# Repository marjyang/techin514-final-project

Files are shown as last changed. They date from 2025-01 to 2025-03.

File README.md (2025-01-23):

# Smart Shower Feedback System

This device focuses on the issue of water usage waste and awareness during long showers - an important issue for utility bills and sustainability.

This system will monitor real-time water usage directly from the shower head (sensing device) and provide feedback to users with a meter and OLED on the other side of the shower wall (display device) to remind users of their water consumption habits. Users will also be able to set weekly water consumption goals.

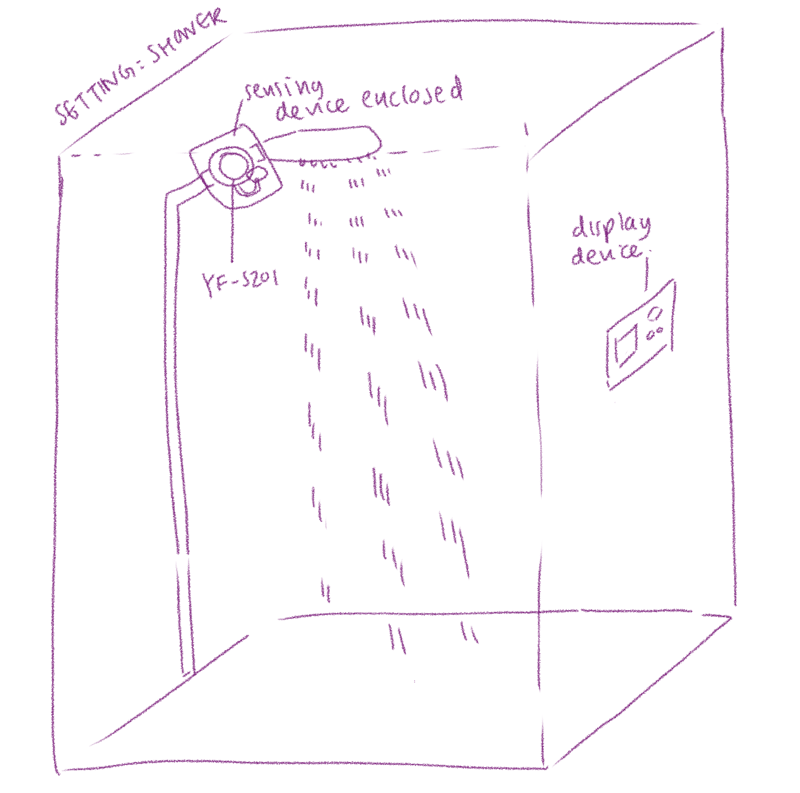
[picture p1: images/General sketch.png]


## The "sensor" device
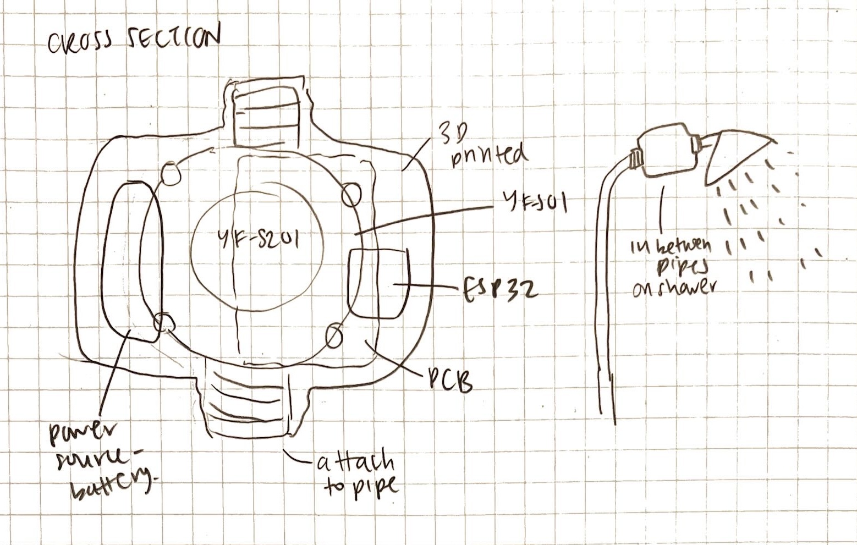
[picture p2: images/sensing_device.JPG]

The sensing device, YF-S201, is connected to the ESP32 from the sensing device, and measures the flow rate of water directly from the showerhead. It generates pulse signals proportional to the water usage, where the ESP32 can process as metrics like total water consumed and flow rate. 

## The "display" device
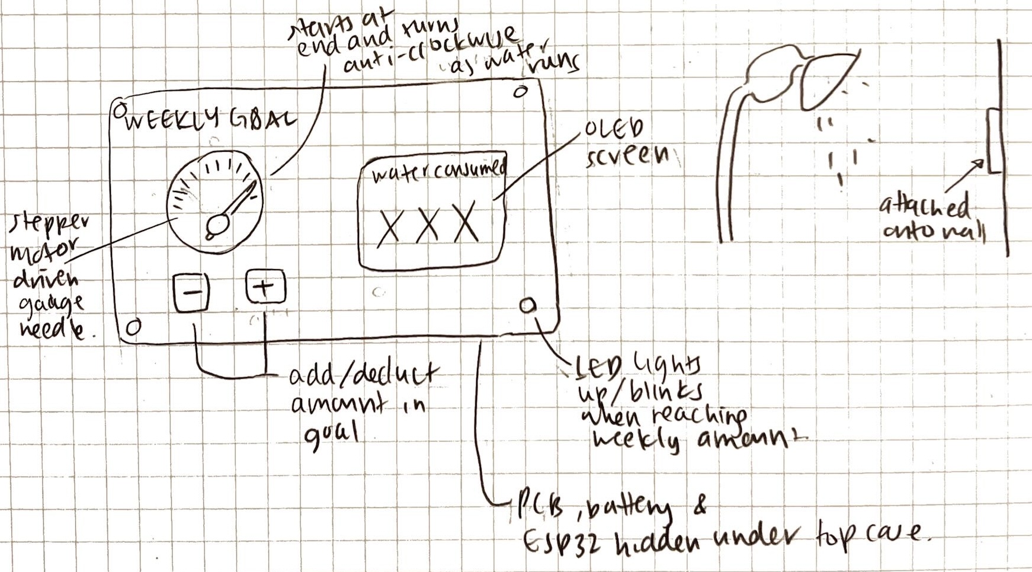
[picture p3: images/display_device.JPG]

The display device has an OLED screen, gauge needle and LEDs controlled by its own ESP32 microcontroller. From the water usage data from the sensing device ESP32, the ESP32 here helps display real-time feedback including water consumed during the week and processes data to track progress toward weekly consumption goal. The buttons connected also allow users to manually adjust the gauge needle or the weekly goal set.

## System Architecture
### Diagram 1
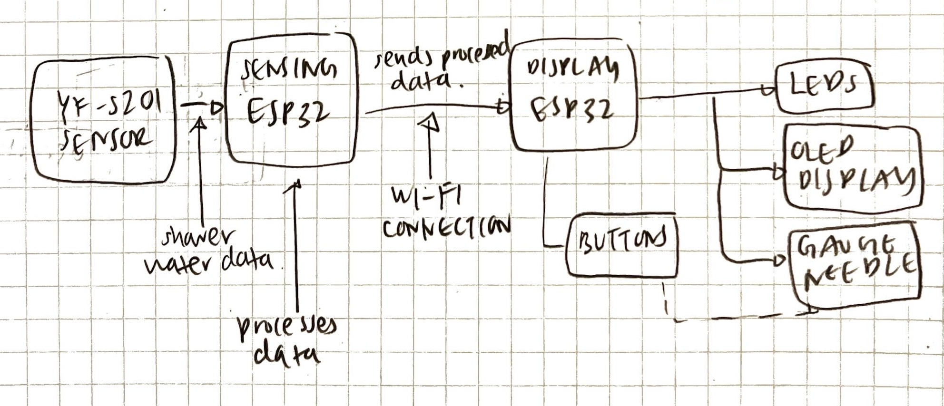
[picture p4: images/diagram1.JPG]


### Diagram 2
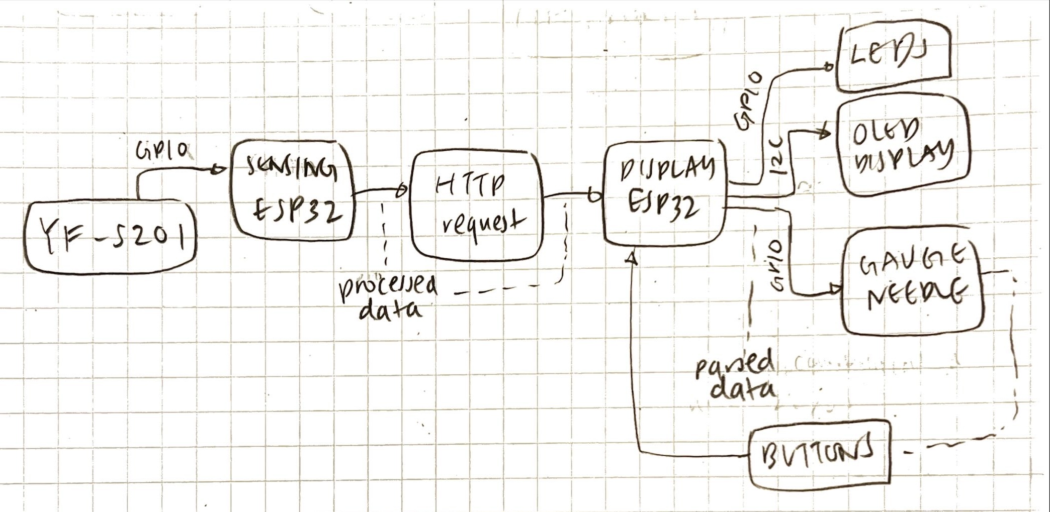
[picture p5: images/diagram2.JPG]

Here, the YF-S201 sensor sends data from the shower through GPIO connection with the sensing device XIAO ESP32, where the data is processed. This ESP32 then through, HTTP request, sends the processed data to the display device ESP32 wirelessly. This ESP32 through GPIO controls the output in the LEDs and another GPIO controlling output in the gauge needle. Through I2C/SPI, the ESP32 displays the processed data onto the SSD1306 OLED display. Buttons are also connected to the GPIO of the ESP32, where input data from interacting with buttons is sent over as data to the gauge needle to control the weekly goal set.

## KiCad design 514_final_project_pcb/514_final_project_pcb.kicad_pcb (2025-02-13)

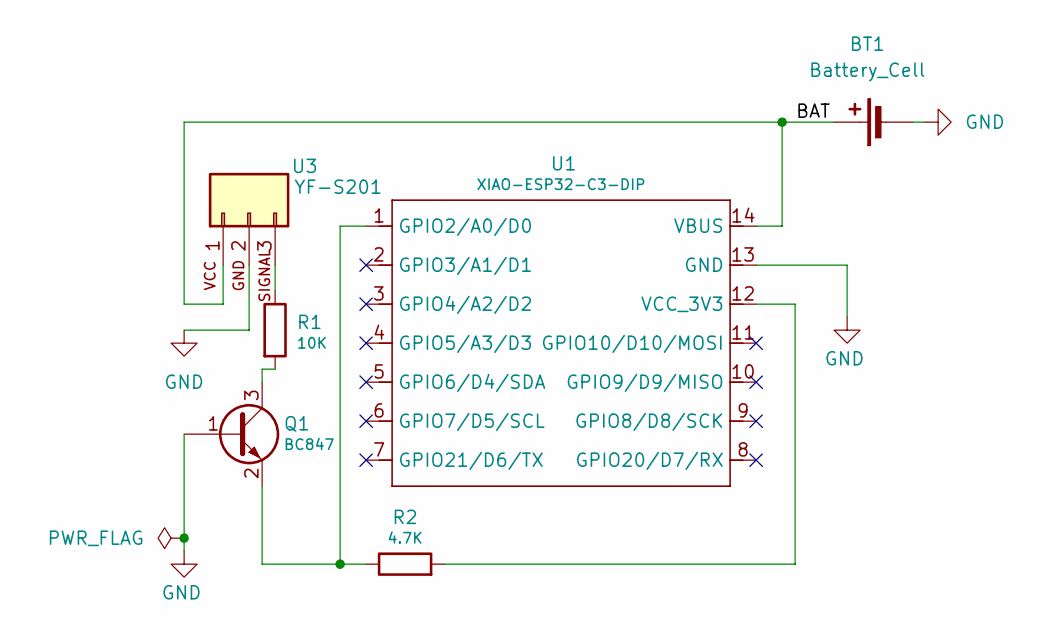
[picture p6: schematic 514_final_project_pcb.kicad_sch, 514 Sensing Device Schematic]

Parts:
BT1: Battery_Cell; JST_NV_B02P-NV_1x02_P5.00mm_Vertical
Q1: BC847; SOT-23
R1: 10K; R_0805_2012Metric
R2: 4.7K; R_0805_2012Metric
U1: XIAO-ESP32-C3-DIP; XIAO-ESP32C3-DIP
U3: YF-S201; PinSocket_1x03_P2.54mm_Vertical

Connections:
/BAT: BT1.1 (+), U1.14 (VBUS), U3.1 (VCC)
GND: BT1.2 (-), Q1.1 (B), U1.13 (GND), U3.2 (GND)
unnamed: Q1.3 (C), R1.2
unnamed: Q1.2 (E), R2.1, U1.1 (GPIO2/A0/D0)
unnamed: R2.2, U1.12 (VCC_3V3)
unnamed: R1.1, U3.3 (SIGNAL)

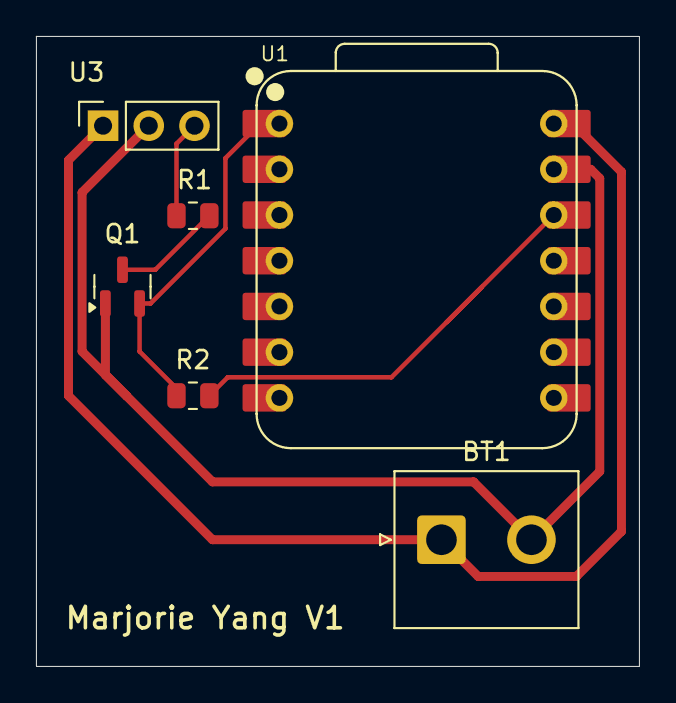
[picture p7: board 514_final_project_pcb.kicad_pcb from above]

Board: 2 copper layers, 33.5 x 35.0 mm, 6 parts (0 on the bottom side), 6 nets.

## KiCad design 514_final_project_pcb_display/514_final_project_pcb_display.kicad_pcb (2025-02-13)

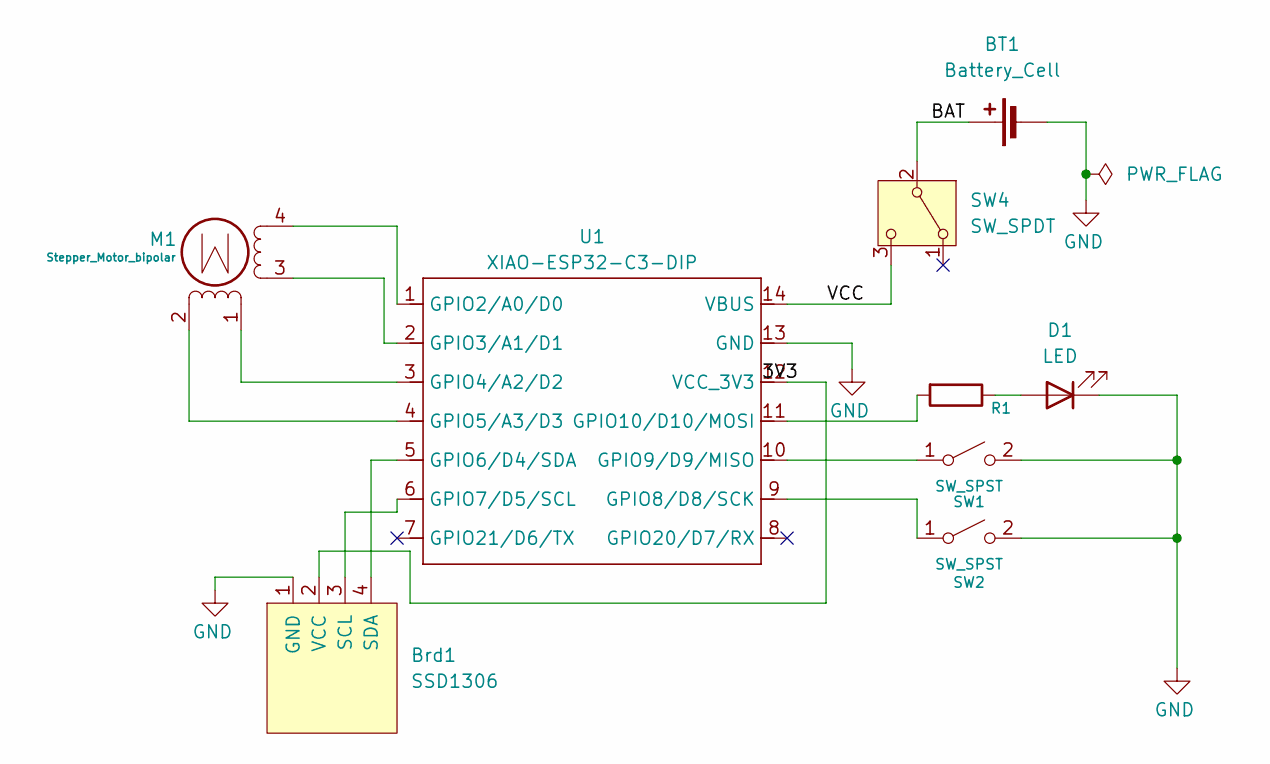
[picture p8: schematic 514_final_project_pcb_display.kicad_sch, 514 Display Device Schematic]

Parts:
BT1: Battery_Cell; JST_NV_B02P-NV_1x02_P5.00mm_Vertical
Brd1: SSD1306; 128x64OLED
D1: LED; LED_1206_3216Metric
M1: Stepper_Motor_bipolar; x27_stepper
R1: 220; R_0603_1608Metric
SW1, SW2: SW_SPST; SW_PUSH-12mm
SW4: SW_SPDT; JST_EH_B3B-EH-A_1x03_P2.50mm_Vertical
U1: XIAO-ESP32-C3-DIP; XIAO-ESP32C3-DIP

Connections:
/BAT: BT1.1 (+), SW4.2 (B)
/VCC: SW4.3 (C), U1.14 (VBUS)
GND: BT1.2 (-), Brd1.1 (GND), D1.1 (K), SW1.2 (B), SW2.2 (B), U1.13 (GND)
unnamed: Brd1.3 (SCL), U1.6 (GPIO7/D5/SCL)
unnamed: Brd1.4 (SDA), U1.5 (GPIO6/D4/SDA)
unnamed: Brd1.2 (VCC), U1.12 (VCC_3V3)
unnamed: D1.2 (A), R1.1
unnamed: M1.2 (-), U1.4 (GPIO5/A3/D3)
unnamed: SW1.1 (A), U1.10 (GPIO9/D9/MISO)
unnamed: SW2.1 (A), U1.9 (GPIO8/D8/SCK)
unnamed: M1.4, U1.1 (GPIO2/A0/D0)
unnamed: M1.3, U1.2 (GPIO3/A1/D1)
unnamed: M1.1, U1.3 (GPIO4/A2/D2)
unnamed: R1.2, U1.11 (GPIO10/D10/MOSI)

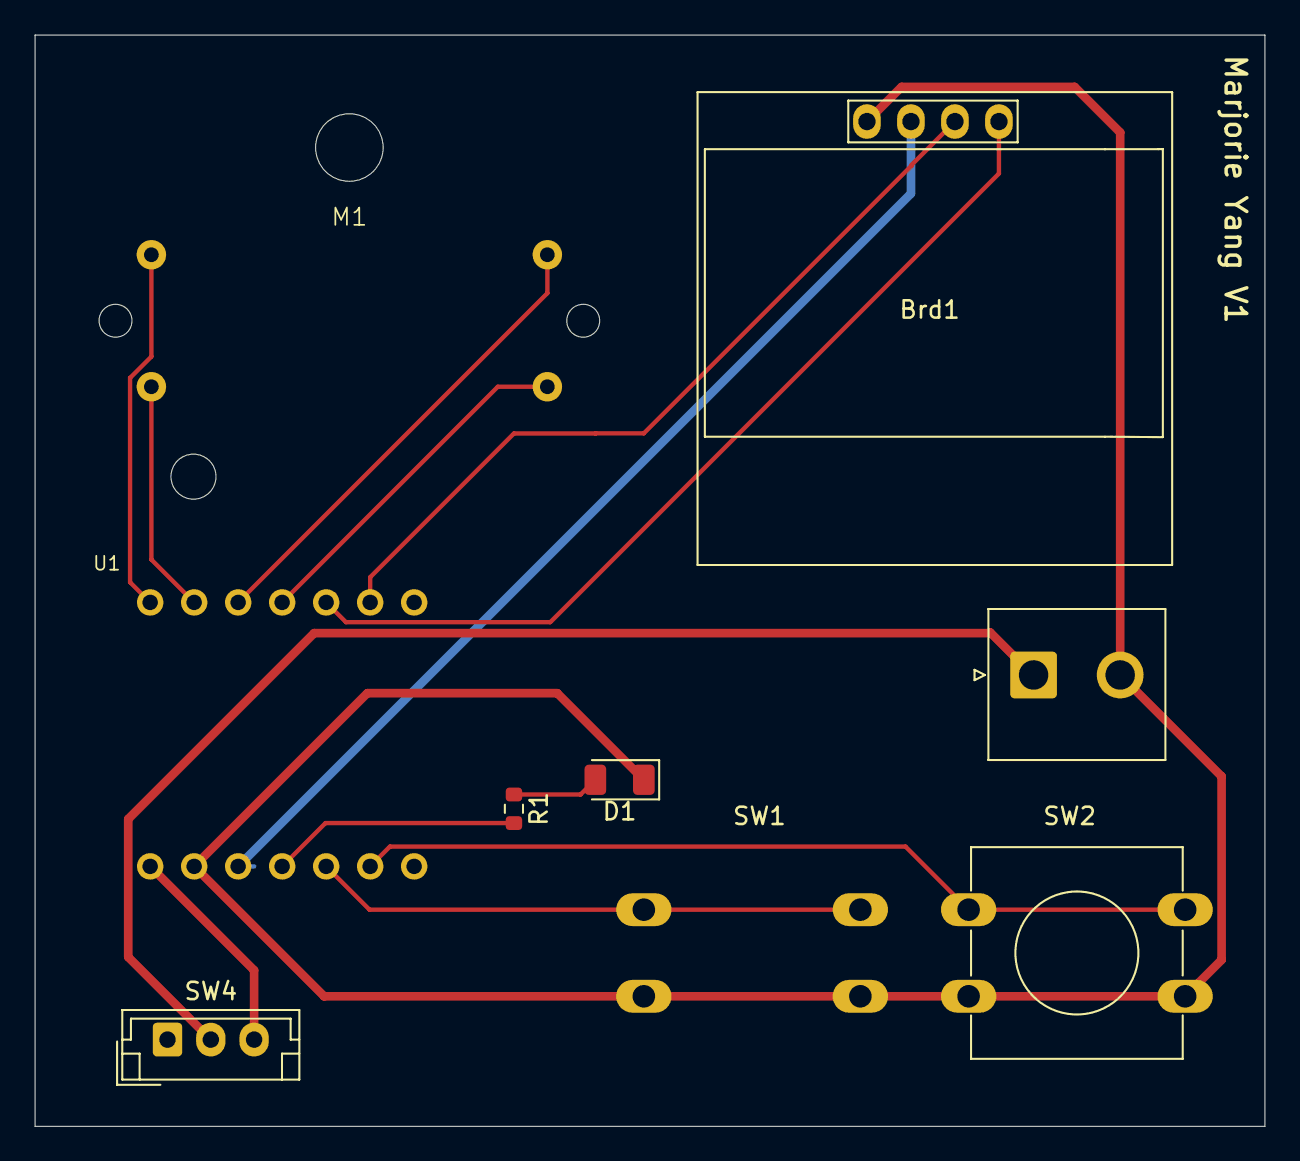
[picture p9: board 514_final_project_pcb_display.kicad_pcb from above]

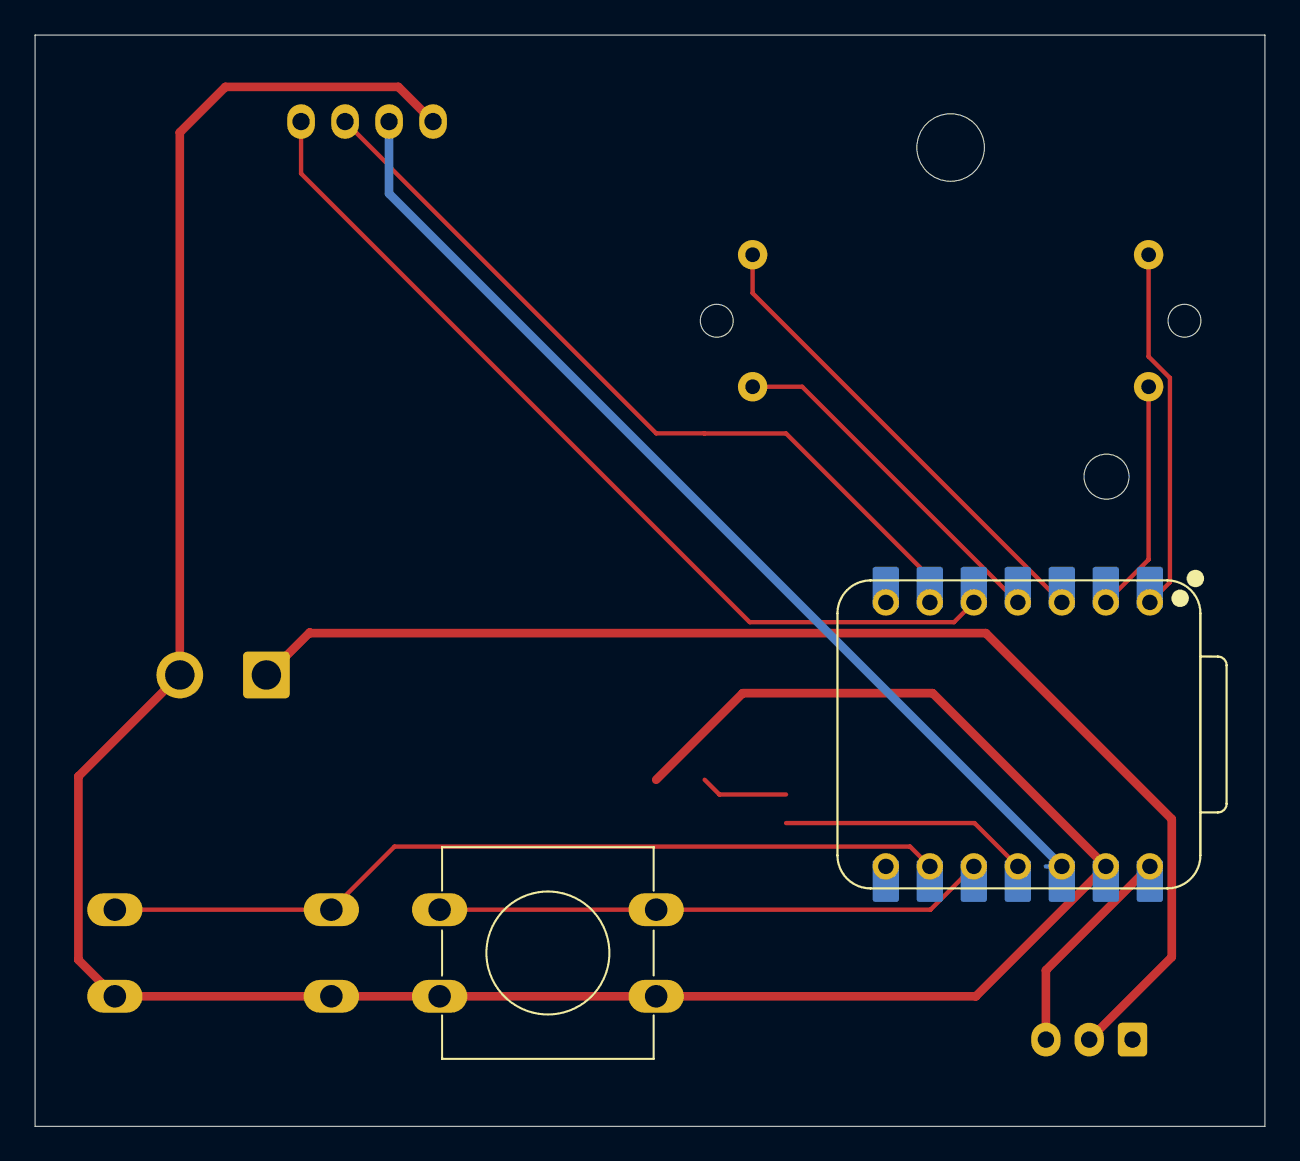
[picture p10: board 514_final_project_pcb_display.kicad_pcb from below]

Board: 2 copper layers, 71.0 x 63.0 mm, 9 parts (2 on the bottom side), 14 nets.

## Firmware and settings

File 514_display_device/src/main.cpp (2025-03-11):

#include <Wire.h>
#include <Adafruit_GFX.h>
#include <Arduino.h>
#include <Adafruit_SSD1306.h>
#include <BLEDevice.h>
#include <BLEUtils.h>
#include <BLEClient.h>
#include <BLEScan.h>
#include <BLEAdvertisedDevice.h>

// **OLED Configuration**
#define SCREEN_WIDTH 128
#define SCREEN_HEIGHT 64
#define OLED_RESET    -1  
#define I2C_ADDRESS   0x3C

#define SDA_PIN 6
#define SCL_PIN 7

Adafruit_SSD1306 display(SCREEN_WIDTH, SCREEN_HEIGHT, &Wire, OLED_RESET);

// **Stepper Motor Configuration**
#define MOTOR_PIN_1 0  
#define MOTOR_PIN_2 1  
#define MOTOR_PIN_3 2  
#define MOTOR_PIN_4 3  

int stepPosition = 0;    // Tracks current stepper position
const int maxSteps = 160; // Maximum stepper position
const int minSteps = 0;   // Minimum stepper position

// **Stepper Motor Step Sequence**
const int stepSequence[4][4] = {
    {1, 0, 1, 0},  
    {0, 1, 1, 0},  
    {0, 1, 0, 1},  
    {1, 0, 0, 1}   
};

// **Water Consumption Variables**
float numerator = 0.0;    // Water consumed
float denominator = 30.0; // Water consumption goal
float initialOffset = 0.0; // Offset to subtract from received values
bool firstDataReceived = false; // Flag to track if we've received initial data

// **Button Pins**
#define BUTTON_UP 8
#define BUTTON_DOWN 9

// **LED Pin**
#define LED_PIN 10  

// **BLE UUIDs**
#define SERVICE_UUID        "6ffd810a-1f60-43df-aa2f-cb68a815285f"
#define CHARACTERISTIC_UUID "7ca0eada-bb21-4d31-8c72-e52221ea4409"

static BLEUUID serviceUUID(SERVICE_UUID);
static BLEUUID charUUID(CHARACTERISTIC_UUID);
static boolean doConnect = false;
static boolean connected = false;
static boolean doScan = false;
static BLEAdvertisedDevice* myDevice;
BLEClient* pClient = NULL;
BLEScan* pBLEScan = NULL;

// **Function Prototypes**
void resetStepper();
void resetStepperToZero();
void moveStepperToPosition(int targetStep);
void moveStepperForward(int steps = 1);
void moveStepperBackward(int steps = 1);
void updateDisplay();
void resetVariables();
bool connectToServer();
void handleButtonPress();

// Reset all variables to starting values
void resetVariables() {
    Serial.println("Resetting variables for new connection");
    initialOffset = 0.0;     // Clear the offset
    numerator = 0.0;         // Reset water consumption
    firstDataReceived = false; // Reset first data flag
    updateDisplay();         // Update the display to show zero
}

// **BLE Client Callback**
class MyClientCallback : public BLEClientCallbacks {
    void onConnect(BLEClient* pClient) { 
        connected = true; 
        Serial.println("✅ Connected to BLE Server!");
    }
    
    void onDisconnect(BLEClient* pClient) { 
        connected = false; 
        Serial.println("❌ Disconnected from BLE Server!");
        // Reset variables when disconnected
        resetVariables();
        doScan = true;  // Restart scanning when disconnected
    }
};

// **BLE Scan Callback**
class MyAdvertisedDeviceCallbacks: public BLEAdvertisedDeviceCallbacks {
    void onResult(BLEAdvertisedDevice advertisedDevice) {
        // Print basic device info
        Serial.print("🔍 BLE Device found: ");
        Serial.print("Name: \"");
        Serial.print(advertisedDevice.getName().c_str());
        Serial.print("\", Address: ");
        Serial.print(advertisedDevice.getAddress().toString().c_str());
        
        // Show RSSI
        Serial.print(", RSSI: ");
        Serial.print(advertisedDevice.getRSSI());
        
        // Check for service UUIDs and print them if available
        if (advertisedDevice.haveServiceUUID()) {
            Serial.print(", Service UUIDs: ");
            for (int i = 0; i < advertisedDevice.getServiceUUIDCount(); i++) {
                Serial.print(advertisedDevice.getServiceUUID(i).toString().c_str());
                Serial.print(" ");
            }
            
            // Extra diagnostic for our specific service UUID
            Serial.print(" [Looking for: ");
            Serial.print(serviceUUID.toString().c_str());
            Serial.print("]");
            
            // Check if device has our service UUID
            if (advertisedDevice.isAdvertisingService(serviceUUID)) {
                Serial.print(" ✓ MATCH FOUND!");
            } else {
                Serial.print(" ✗ No match");
            }
        } else {
            Serial.print(", No Service UUIDs advertised");
        }
        
        Serial.println();
        
        // Connect if it's our device
        if (advertisedDevice.haveServiceUUID() && advertisedDevice.isAdvertisingService(serviceUUID)) {
            BLEDevice::getScan()->stop();
            myDevice = new BLEAdvertisedDevice(advertisedDevice);
            doConnect = true;
            doScan = false;
            Serial.println("🎯 Found our water tracker device! Connecting...");
        }
    }
};

// **BLE Notification Callback**
static void notifyCallback(
    BLERemoteCharacteristic* pRemoteCharacteristic,
    uint8_t* pData,
    size_t length,
    bool isNotify) {

    Serial.println("\n📥 BLE Notification Received! 📥");
    Serial.print("Characteristic UUID: ");
    Serial.println(pRemoteCharacteristic->getUUID().toString().c_str());
    Serial.print("Data Length: ");
    Serial.println(length);

    // Print raw byte data in multiple formats
    Serial.println("🔍 RAW DATA:");
    Serial.print("   HEX: ");
    for (size_t i = 0; i < length; i++) {
        Serial.print(pData[i], HEX);
        Serial.print(" ");
    }
    Serial.println();
    
    Serial.print("   DEC: ");
    for (size_t i = 0; i < length; i++) {
        Serial.print((int)pData[i]);
        Serial.print(" ");
    }
    Serial.println();
    
    Serial.print("   ASCII: ");
    for (size_t i = 0; i < length; i++) {
        if (pData[i] >= 32 && pData[i] <= 126) { // Printable ASCII
            Serial.print((char)pData[i]);
        } else {
            Serial.print(".");
        }
    }
    Serial.println();

    // Convert raw bytes to a string
    String receivedData = "";
    for (size_t i = 0; i < length; i++) {
        receivedData += (char)pData[i];
    }

    Serial.print("📝 String Representation: '");
    Serial.print(receivedData);
    Serial.println("'");

    // Try to convert the received string to a float
    float totalLiters = 0.0;
    bool validData = true;
    
    // Basic validation to check if data is a valid number
    for (size_t i = 0; i < receivedData.length(); i++) {
        char c = receivedData.charAt(i);
        if (!isdigit(c) && c != '.' && c != '-') {
            validData = false;
            Serial.print("Invalid character detected: '");
            Serial.print(c);
            Serial.print("' at position ");
            Serial.println(i);
            break;
        }
    }
    
    if (validData) {
        totalLiters = atof(receivedData.c_str());
        Serial.print("✅ Parsed as Number: ");
        Serial.println(totalLiters);
    } else {
        Serial.println("⚠️ Invalid data format received! Could not parse as number.");
        return;
    }

    if (totalLiters >= 0) {  
        // If this is the first data received, set the offset
        if (!firstDataReceived) {
            initialOffset = totalLiters;
            firstDataReceived = true;
            Serial.print("📏 Set initial offset to: ");
            Serial.println(initialOffset);
        }
        
        // Apply offset to the received value
        float adjustedLiters = totalLiters - initialOffset;
        if (adjustedLiters < 0) adjustedLiters = 0;  // Ensure we don't go negative
        
        Serial.print("✅ Raw Water Consumption: ");
        Serial.print(totalLiters);
        Serial.println(" L");
        
        Serial.print("✅ Adjusted Water Consumption: ");
        Serial.print(adjustedLiters);
        Serial.println(" L");

        numerator = adjustedLiters;  // Store water consumed as float
        Serial.print("Current Goal: ");
        Serial.print(denominator);
        Serial.println(" L");

        // Calculate the stepper position based on the water consumption ratio
        int targetStep = map(numerator * 10, 0, denominator * 10, minSteps, maxSteps); // Multiply by 10 for better precision
        targetStep = constrain(targetStep, minSteps, maxSteps); 

        Serial.print("🚀 Moving Stepper to Step: ");
        Serial.print(targetStep);
        Serial.print(" (from ");
        Serial.print(stepPosition);
        Serial.println(")");

        moveStepperToPosition(targetStep);
        updateDisplay();
    } else {
        Serial.println("⚠️ Failed to process BLE Data! Negative value received.");
    }
}

// **BLE Connection Function**
bool connectToServer() {
    Serial.println("\n🔌 CONNECTING TO BLE SERVER 🔌");
    Serial.print("Device Address: ");
    Serial.println(myDevice->getAddress().toString().c_str());
    Serial.print("Device Name: ");
    Serial.println(myDevice->getName().c_str());
    
    // List all advertised services
    Serial.println("Advertised Services:");
    if (myDevice->haveServiceUUID()) {
        for (int i = 0; i < myDevice->getServiceUUIDCount(); i++) {
            Serial.print("  - ");
            Serial.println(myDevice->getServiceUUID(i).toString().c_str());
        }
    } else {
        Serial.println("  No services advertised");
    }

    // Clean up previous client if it exists
    if (pClient != NULL) {
        delete pClient;
    }
    
    pClient = BLEDevice::createClient();
    pClient->setClientCallbacks(new MyClientCallback());

    // Connect to the remote BLE Server
    Serial.println("Attempting connection...");
    if (!pClient->connect(myDevice)) {
        Serial.println("❌ Failed to connect to BLE server.");
        return false;
    }
    Serial.println("Connected to device!");

    // Discover all services on device
    Serial.println("\n📋 DISCOVERING SERVICES 📋");
    pClient->getServices();
    
    // Obtain a reference to the service we are after
    Serial.print("Looking for service UUID: ");
    Serial.println(serviceUUID.toString().c_str());
    
    BLERemoteService* pRemoteService = pClient->getService(serviceUUID);
    if (pRemoteService == nullptr) {
        Serial.println("❌ Failed to find our target service!");
        Serial.println("Available services on device:");
        
        // List all available services for debugging
        std::map<std::string, BLERemoteService*>* serviceMap = pClient->getServices();
        for(std::map<std::string, BLERemoteService*>::iterator it = serviceMap->begin(); it != serviceMap->end(); ++it) {
            Serial.print("  - ");
            Serial.println(it->first.c_str());
        }
        
        pClient->disconnect();
        return false;
    }
    Serial.println("✅ Found our service!");

    // Find all characteristics for this service
    Serial.println("\n🔍 DISCOVERING CHARACTERISTICS 🔍");
    Serial.print("Looking for characteristic UUID: ");
    Serial.println(charUUID.toString().c_str());
    
    // List all characteristics of the service
    std::map<std::string, BLERemoteCharacteristic*>* charMap = pRemoteService->getCharacteristics();
    Serial.println("Available characteristics:");
    for(std::map<std::string, BLERemoteCharacteristic*>::iterator it = charMap->begin(); it != charMap->end(); ++it) {
        Serial.print("  - ");
        Serial.print(it->first.c_str());
        
        // Show properties
        BLERemoteCharacteristic* pChar = it->second;
        Serial.print(" (Properties: ");
        if(pChar->canRead()) Serial.print("READ ");
        if(pChar->canWrite()) Serial.print("WRITE ");
        if(pChar->canNotify()) Serial.print("NOTIFY ");
        if(pChar->canIndicate()) Serial.print("INDICATE ");
        Serial.println(")");
    }
    
    // Obtain a reference to our target characteristic
    BLERemoteCharacteristic* pRemoteCharacteristic = pRemoteService->getCharacteristic(charUUID);
    if (pRemoteCharacteristic == nullptr) {
        Serial.println("❌ Failed to find our target characteristic!");
        pClient->disconnect();
        return false;
    }
    Serial.println("✅ Found our characteristic!");

    // Read initial value if possible
    if (pRemoteCharacteristic->canRead()) {
        std::string value = pRemoteCharacteristic->readValue();
        Serial.println("\n📊 INITIAL DATA READING 📊");
        Serial.print("Raw value: '");
        Serial.print(value.c_str());
        Serial.println("'");
        
        // Show bytes in hex for debugging
        Serial.print("Hex: ");
        for (int i = 0; i < value.length(); i++) {
            Serial.print((uint8_t)value[i], HEX);
            Serial.print(" ");
        }
        Serial.println();
    } else {
        Serial.println("❗ Characteristic is not readable");
    }

    // Register for notifications if supported
    if (pRemoteCharacteristic->canNotify()) {
        pRemoteCharacteristic->registerForNotify(notifyCallback);
        Serial.println("✅ Successfully registered for notifications");
    } else {
        Serial.println("❗ Characteristic does not support notifications");
    }

    Serial.println("\n✅ BLE CONNECTION COMPLETE ✅");
    connected = true;
    return true;
}

// **Initialize stepper to zero position - turns back 170 steps**
void resetStepperToZero() {
    Serial.println("🔄 Initializing stepper motor - moving backward 170 steps");
    digitalWrite(LED_PIN, HIGH);  // Turn on LED during reset

    // Move backward 170 steps regardless of current position
    for (int i = 0; i < 170; i++) {
        moveStepperBackward(1);
        delay(10);  // Small delay between steps
    }
    
    // Reset position counter
    stepPosition = 0;
    
    digitalWrite(LED_PIN, LOW);  // Turn off LED when done
    Serial.println("✅ Stepper reset complete");
}

// **Reset Stepper Based on Water Consumption Ratio**
void resetStepper() {
    Serial.println("Resetting stepper to match water consumed ratio...");
    digitalWrite(LED_PIN, HIGH);

    // Calculate target step based on current water ratio
    int targetStep = map(numerator * 10, 0, denominator * 10, minSteps, maxSteps);
    targetStep = constrain(targetStep, minSteps, maxSteps);
    
    moveStepperToPosition(targetStep); 

    digitalWrite(LED_PIN, LOW);
    updateDisplay();
}

// **Move Stepper to Specific Position**
void moveStepperToPosition(int targetStep) {
    Serial.print("🚀 Moving Stepper to Position: ");
    Serial.println(targetStep);

    targetStep = constrain(targetStep, minSteps, maxSteps);

    // More efficient movement by calculating number of steps needed
    int stepsToMove = targetStep - stepPosition;
    
    if (stepsToMove > 0) {
        moveStepperForward(stepsToMove);
    } else if (stepsToMove < 0) {
        moveStepperBackward(abs(stepsToMove));
    }
    
    stepPosition = targetStep;
}

// **Stepper Motor Control Functions - Optimized for multi-step movement**
void moveStepperForward(int steps) {
    for (int i = 0; i < steps; i++) {
        for (int step = 0; step < 4; step++) {
            digitalWrite(MOTOR_PIN_1, stepSequence[step][0]);
            digitalWrite(MOTOR_PIN_2, stepSequence[step][1]);
            digitalWrite(MOTOR_PIN_3, stepSequence[step][2]);
            digitalWrite(MOTOR_PIN_4, stepSequence[step][3]);
            delay(10);
        }
    }
}

void moveStepperBackward(int steps) {
    for (int i = 0; i < steps; i++) {
        for (int step = 0; step < 4; step++) {
            int s = 3 - step;
            digitalWrite(MOTOR_PIN_1, stepSequence[s][0]);
            digitalWrite(MOTOR_PIN_2, stepSequence[s][1]);
            digitalWrite(MOTOR_PIN_3, stepSequence[s][2]);
            digitalWrite(MOTOR_PIN_4, stepSequence[s][3]);
            delay(10);
        }
    }
}

// **Update OLED Display with Progress Bar**
void updateDisplay() {
    display.clearDisplay();
    
    // Title
    display.setTextSize(1);
    display.setTextColor(SSD1306_WHITE);
    display.setCursor(0, 0);
    display.println("Water Consumption:");
    
    // Water values with decimals
    display.setTextSize(2);
    display.setCursor(5, 16);
    
    // Format numbers with 1 decimal place
    char waterValue[16];
    char goalValue[16];
    dtostrf(numerator, 4, 1, waterValue); // Convert float to string with 1 decimal
    dtostrf(denominator, 4, 1, goalValue); // Convert float to string with 1 decimal
    
    // Remove leading spaces that dtostrf might add
    char* trimmedWater = waterValue;
    while(*trimmedWater == ' ') trimmedWater++;
    
    char* trimmedGoal = goalValue;
    while(*trimmedGoal == ' ') trimmedGoal++;
    
    // Display the formatted water values
    display.print(trimmedWater);
    display.print("/");
    display.print(trimmedGoal);
    display.println("L");

    // Draw a progress bar
    int barWidth = map(numerator * 10, 0, denominator * 10, 0, 108); // Multiply by 10 for better precision
    barWidth = constrain(barWidth, 0, 108);
    display.drawRect(10, 40, 108, 15, SSD1306_WHITE);
    display.fillRect(10, 40, barWidth, 15, SSD1306_WHITE);
    
    // Show percentage
    float percentage = (numerator / denominator) * 100.0;
    display.setTextSize(1);
    display.setCursor(40, 56);
    display.print(percentage, 1); // Display percentage with 1 decimal place
    display.print("% Full");
    
    display.display();
}

// **Button Press Handling**
void handleButtonPress() {
    // Non-blocking button checking
    static unsigned long lastButtonTime = 0;
    unsigned long currentTime = millis();
    
    if (currentTime - lastButtonTime >= 200) {  // Debounce time
        if (digitalRead(BUTTON_UP) == LOW) {
            denominator += 2.5; 
            if (denominator > 100.0) denominator = 100.0;  // Limit max goal
            Serial.print("🎯 New Goal: ");
            Serial.println(denominator);
            updateDisplay();
            lastButtonTime = currentTime;
        }

        if (digitalRead(BUTTON_DOWN) == LOW) {
            denominator -= 2.5;
            if (denominator < 5.0) denominator = 5.0;  // Avoid zero
            Serial.print("🎯 New Goal: ");
            Serial.println(denominator);
            updateDisplay();
            lastButtonTime = currentTime;
        }
    }
}

// **Setup Function**
void setup() {
    Serial.begin(115200);
    Serial.println("\n\n🚀 Starting up water tracker device...");
    delay(1000);

    // Initialize I2C and OLED
    Wire.begin(SDA_PIN, SCL_PIN);
    if(!display.begin(SSD1306_SWITCHCAPVCC, I2C_ADDRESS)) {
        Serial.println("SSD1306 allocation failed");
        for(;;); // Don't proceed, loop forever
    }
    
    // Set up IO pins
    pinMode(BUTTON_UP, INPUT_PULLUP);
    pinMode(BUTTON_DOWN, INPUT_PULLUP);
    pinMode(LED_PIN, OUTPUT);
    pinMode(MOTOR_PIN_1, OUTPUT);
    pinMode(MOTOR_PIN_2, OUTPUT);
    pinMode(MOTOR_PIN_3, OUTPUT);
    pinMode(MOTOR_PIN_4, OUTPUT);

    // Reset all variables to starting values
    resetVariables();

    // Show startup message
    display.clearDisplay();
    display.setTextSize(1);
    display.setTextColor(SSD1306_WHITE);
    display.setCursor(0, 0);
    display.println("Water Tracker");
    display.println("Starting...");
    display.println("Initializing motor");
    display.display();

    // First reset stepper to zero position by moving back 170 steps
    resetStepperToZero();
    
    // Update display with zeroed position
    updateDisplay();
    
    display.setCursor(0, 40);
    display.println("Setting up BLE...");
    display.display();

    // Initialize BLE
    BLEDevice::init("Display_Device");
    
    // Initialize BLE scan
    pBLEScan = BLEDevice::getScan();
    pBLEScan->setAdvertisedDeviceCallbacks(new MyAdvertisedDeviceCallbacks());
    pBLEScan->setActiveScan(true);
    pBLEScan->setInterval(100);
    pBLEScan->setWindow(99);
    
    // Begin scanning for BLE devices
    doScan = true;
    
    Serial.println("✅ Setup complete, ready to track water consumption!");
}

// **Loop Function - Non-blocking design**
void loop() {
    // Handle BLE connection
    if (doConnect) {
        Serial.println("🔗 Attempting to connect to BLE Server...");
        if (connectToServer()) {
            Serial.println("✅ Connected to BLE Server!");
        } else {
            Serial.println("❌ BLE Connection Failed! Retrying...");
            doScan = true;  // Restart scanning
        }
        doConnect = false;
    }

    // If disconnected, restart BLE scan
    if (!connected && doScan) {
        Serial.println("\n🔎 SCANNING FOR BLE DEVICES...");
        Serial.print("Looking for Service UUID: ");
        Serial.println(serviceUUID.toString().c_str());
        
        // Set active scanning for better results
        pBLEScan->setActiveScan(true);
        pBLEScan->setInterval(100);
        pBLEScan->setWindow(99);
        
        // Start scan with longer duration (10 seconds)
        pBLEScan->start(10, false);
        
        // No direct error check as start() returns BLEScanResults, not bool
        
        doScan = false;  // Don't start another scan until this one finishes
    }

    // Check for button presses to update the water goal
    handleButtonPress();

    // Refresh display periodically (e.g., every 1 second)
    static unsigned long lastUpdate = 0;
    unsigned long currentMillis = millis();
    
    if (currentMillis - lastUpdate > 1000) {
        Serial.println("🔄 Updating Display...");
        updateDisplay();
        lastUpdate = currentMillis;
    }

    // Small delay to prevent CPU hogging
    delay(50);
}

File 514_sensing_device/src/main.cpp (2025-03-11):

#include <Arduino.h>
#include <BLEDevice.h>
#include <BLEServer.h>
#include <BLEUtils.h>
#include <BLE2902.h>

#define FLOW_SENSOR_PIN 2  // Directly connected to YF-S201 signal pin

// BLE Server Variables
BLEServer* pServer = NULL;
BLECharacteristic* pCharacteristic = NULL;
bool deviceConnected = false;
bool oldDeviceConnected = false;
unsigned long previousMillis = 0;
const long interval = 1000;  // BLE update interval (1 second)

// Flow Sensor Variables
volatile uint16_t pulseCount = 0;
float flowRate = 0.0;
float totalLiters = 0.0;
unsigned long lastTime = 0;

// BLE UUIDs
#define SERVICE_UUID        "6ffd810a-1f60-43df-aa2f-cb68a815285f"  // Unique service ID
#define CHARACTERISTIC_UUID "7ca0eada-bb21-4d31-8c72-e52221ea4409"  // Unique characteristic ID

// Interrupt Service Routine (ISR) for Flow Sensor
void IRAM_ATTR countPulse() {
    pulseCount++;
}

// BLE Server Callbacks
class MyServerCallbacks : public BLEServerCallbacks {
    void onConnect(BLEServer* pServer) {
        deviceConnected = true;
    };

    void onDisconnect(BLEServer* pServer) {
        deviceConnected = false;
    }
};

void setup() {
    Serial.begin(115200);
    delay(3000); 
    Serial.println("Initializing BLE...");
    // Setup Flow Sensor
    pinMode(FLOW_SENSOR_PIN, INPUT_PULLUP);
    attachInterrupt(digitalPinToInterrupt(FLOW_SENSOR_PIN), countPulse, FALLING);  // Detect pulses

    // Setup BLE Server
    BLEDevice::init("YF-S201_Sensor");
    Serial.println("BLE Device Initialized as: YF-S201_Sensor");
    pServer = BLEDevice::createServer();
    pServer->setCallbacks(new MyServerCallbacks());

    BLEService *pService = pServer->createService(SERVICE_UUID);
    pCharacteristic = pService->createCharacteristic(
        CHARACTERISTIC_UUID,
        BLECharacteristic::PROPERTY_READ |
        BLECharacteristic::PROPERTY_NOTIFY
    );
    pCharacteristic->addDescriptor(new BLE2902());

    pService->start();

    // Start advertising BLE service
    BLEAdvertising *pAdvertising = BLEDevice::getAdvertising();
    pAdvertising->addServiceUUID(SERVICE_UUID);
    pAdvertising->setScanResponse(true);
    pAdvertising->setMinPreferred(0x06);
    pAdvertising->setMinPreferred(0x12);
    BLEDevice::startAdvertising();
    Serial.println("BLE is now advertising...");
    
    Serial.println("BLE Server Started. Waiting for connections...");
}

void loop() {
    unsigned long currentTime = millis();

    if (currentTime - lastTime >= 1000) {  // Every second
        detachInterrupt(FLOW_SENSOR_PIN);

        // Convert pulse count to flow rate in L/min
        flowRate = (pulseCount / 7.5);
        if (flowRate > 50.0) {  // 🚨 Limit max realistic flow rate
            Serial.println("⚠️ Warning: Unrealistic flow rate detected!");
            flowRate = 0.0;  // Ignore this reading
        }
        // Calculate total volume (Liters)
        totalLiters += (flowRate / 60.0); // Convert L/min to liters per second

        Serial.print("Flow Rate: ");
        Serial.print(flowRate);
        Serial.print(" L/min, Total Accumulated: ");
        Serial.print(totalLiters);
        Serial.println(" L");

        pulseCount = 0;  // Reset count
        lastTime = currentTime;

        attachInterrupt(digitalPinToInterrupt(FLOW_SENSOR_PIN), countPulse, FALLING);

        // Send data via BLE if connected
        if (deviceConnected) {
            char buffer[20];
            memset(buffer, 0, sizeof(buffer)); // Clear buffer to prevent corruption
            snprintf(buffer, sizeof(buffer), "%.2f", totalLiters);

            Serial.print("Sending BLE Data: ");
            Serial.println(buffer);  // Debug print to confirm full message is sent

            pCharacteristic->setValue(buffer);
            pCharacteristic->notify();
        }
    }

    // Manage BLE connection status
    if (!deviceConnected && oldDeviceConnected) {
        delay(500);
        pServer->startAdvertising();
        Serial.println("Restarting BLE Advertising...");
        oldDeviceConnected = deviceConnected;
    }

    if (deviceConnected && !oldDeviceConnected) {
        oldDeviceConnected = deviceConnected;
    }

    delay(1000);
}

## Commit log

2025-01-27 added pcb schematic kicad
    [514_final_project_pcb.kicad_pcb, 514_final_project_pcb.kicad_sch]
2025-02-13 updated files
    [514_final_project_pcb.kicad_pcb, 514_final_project_pcb.kicad_sch, 514_final_project_pcb_display.kicad_pcb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]
